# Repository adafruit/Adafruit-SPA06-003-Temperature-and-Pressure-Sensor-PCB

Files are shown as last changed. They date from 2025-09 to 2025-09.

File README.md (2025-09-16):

## Adafruit SPA06-003 Temperature + Pressure Sensor - STEMMA QT PCB

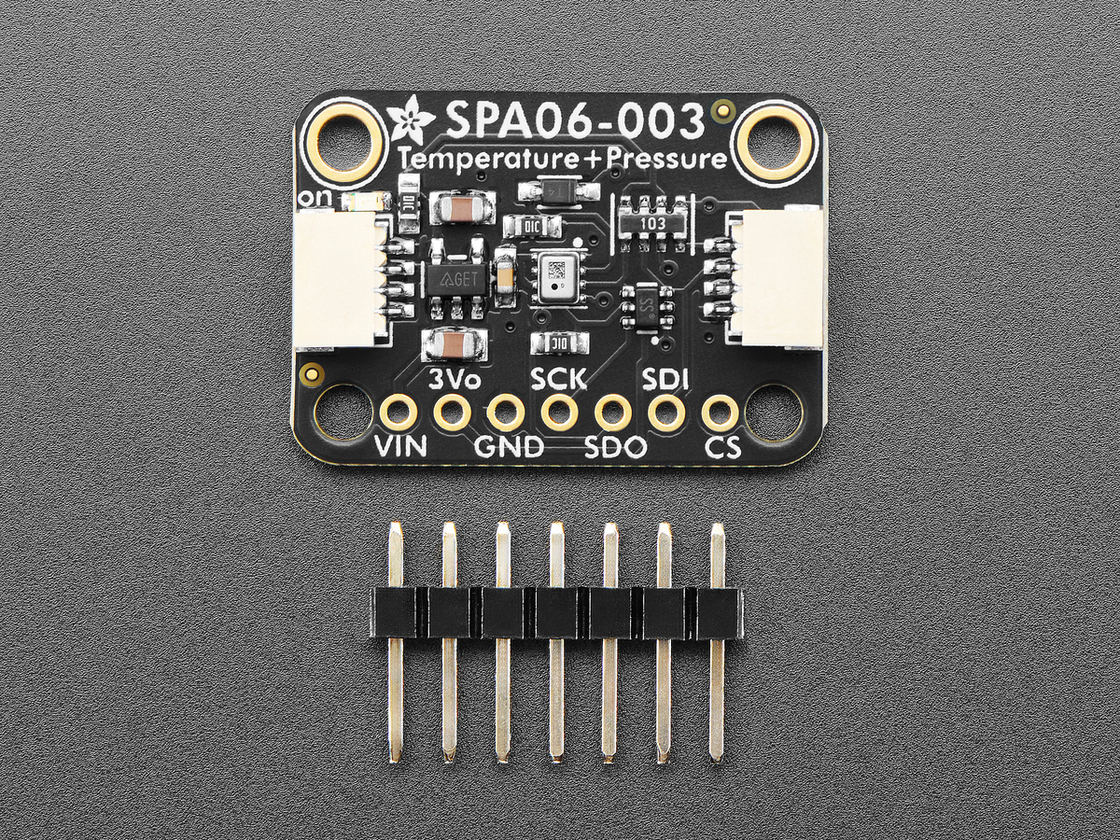
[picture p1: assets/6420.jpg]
<a href="http://www.adafruit.com/products/6420"><br/>
Click here to purchase one from the Adafruit shop</a>

PCB files for the Adafruit SPA06-003 Temperature + Pressure Sensor - STEMMA QT. 

Format is EagleCAD schematic and board layout
* https://www.adafruit.com/product/6420

### Description

This pressure sensor from Goertek is a good low-cost sensing solution for measuring barometric pressure. If you need excellent accuracy and repeatability for altitude calculations, [you can't beat the Bosch BMP series](https://www.adafruit.com/search?q=bmp) - but if you are doing basic DIY sensing, this sensor fits the bill. We see it used a lot for DIY quad copter builds and environmental sensing.

The SPA06-003 can measure from 300~1100hPa (approximately -500 to +9000m from sea level) with typical relative accuracy of ±3 Pa (equivalent to ±0.25 meter) and absolute accuracy of ±30 Pascals, or ±2.5meters. Temperature measurement accuracy is ±1°C. As we mentioned, its not going to be as accurate or precise as the latest BMP series, but the price can't be beat!

Nice sensor right? So we made it easy for you to get right into your next project. The surface-mount sensor is soldered onto a PCB and comes with a 3.3V regulator and level shifting so you can use it with a 3V or 5V logic microcontroller or single board computer without worry.

The custom made PCB is in the [STEMMA QT form factor](https://www.adafruit.com/?q=stemma%20qt%20sensor), making them easy to interface with. The [STEMMA QT connectors](https://learn.adafruit.com/introducing-adafruit-stemma-qt/what-is-stemma-qt) on either side are compatible with the [SparkFun Qwiic](https://www.sparkfun.com/qwiic) I2C connectors. This allows you to make solderless connections between your development board and the SPA06 or to chain it with a wide range of other sensors and accessories using a [compatible cable](https://www.adafruit.com/?q=stemma%20qt%20cable). [QT Cable is not included, but we have a variety in the shop](https://www.adafruit.com/?q=stemma+qt+cable&sort=BestMatch).

### License

Adafruit invests time and resources providing this open source design, please support Adafruit and open-source hardware by purchasing products from [Adafruit](https://www.adafruit.com)!

Designed by Limor Fried/Ladyada for Adafruit Industries.

Creative Commons Attribution/Share-Alike, all text above must be included in any redistribution. 
See license.txt for additional details.

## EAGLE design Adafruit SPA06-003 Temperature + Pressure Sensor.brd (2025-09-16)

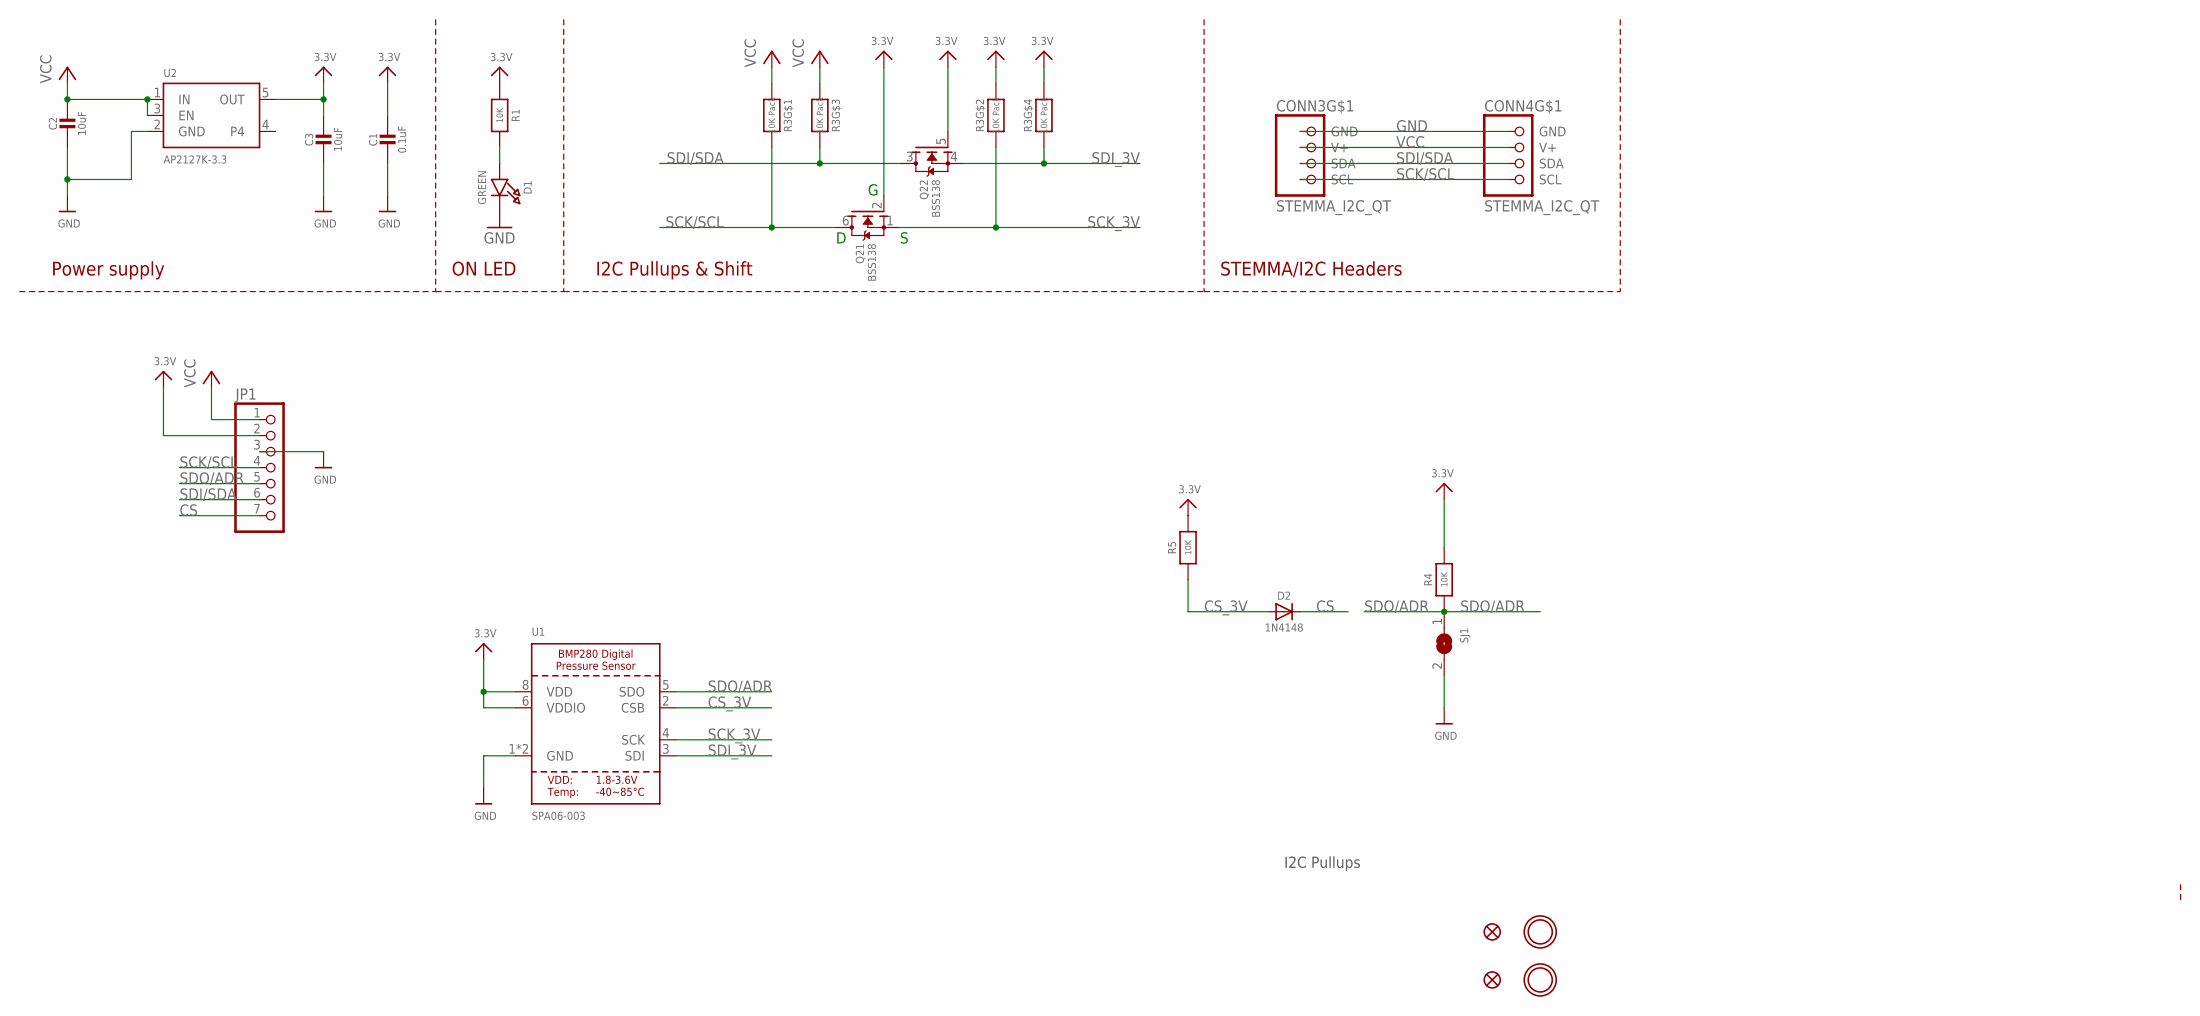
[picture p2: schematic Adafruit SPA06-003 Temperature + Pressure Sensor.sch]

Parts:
C1: 0.1uF; 0603-NO
C2, C3: 10uF; 0805-NO
CONN3, CONN4: STEMMA_I2C_QT; JST_SH4
D1: GREEN; CHIPLED_0603_NOOUTLINE
D2: 1N4148; SOD-323
FID3, FID4: FIDUCIAL_0.5MM
JP1: HEADER-1X770MIL; 1X07_ROUND_70
Q2: BSS138; SOT363
R1, R4, R5: 10K; 0603-NO
R3: 10K Pack; RESPACK_4X0603
SJ1: SOLDERJUMPER; SOLDERJUMPER_ARROW_NOPASTE
U1: SPA06-003; BMX280_COMBO
U2: AP2127K-3.3; SOT23-5
U$1, U$17: MOUNTINGHOLE2.5; MOUNTINGHOLE_2.5_PLATED

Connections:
3.3V: C1.1, C3.1, JP1.2, Q2.2 (G), Q2.5 (G), R1.1, R3.2 (1), R3.4 (1), R4.2, R5.2, U1.6 (VDDIO), U1.8 (VDD), U2.5 (OUT)
CS: D2.C, JP1.7
CS_3V: D2.A, R5.1, U1.2 (CSB)
GND: C1.2, C2.2, C3.2, CONN3.1 (GND), CONN4.1 (GND), D1.C, JP1.3, SJ1.2, U1.1 (GND), U1.7 (GND), U2.2 (GND)
unnamed: D1.A, R1.2
SCK/SCL: CONN3.4 (SCL), CONN4.4 (SCL), JP1.4, Q2.6 (D), R3.8 (2)
SCK_3V: Q2.1 (S), R3.7 (2), U1.4 (SCK)
SDI/SDA: CONN3.3 (SDA), CONN4.3 (SDA), JP1.6, Q2.3 (D), R3.6 (2)
SDI_3V: Q2.4 (S), R3.5 (2), U1.3 (SDI)
SDO/ADR: JP1.5, R4.1, SJ1.1, U1.5 (SDO)
VCC: C2.1, CONN3.2 (V+), CONN4.2 (V+), JP1.1, R3.1, R3.3 (1), U2.1 (IN), U2.3 (EN)

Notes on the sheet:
I2C Pullups & Shift
STEMMA/I2C Headers
ON LED
Power supply
I2C Pullups

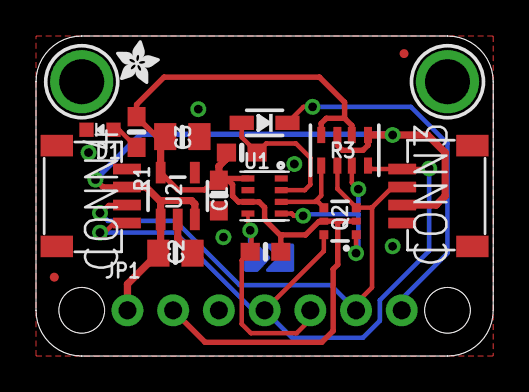
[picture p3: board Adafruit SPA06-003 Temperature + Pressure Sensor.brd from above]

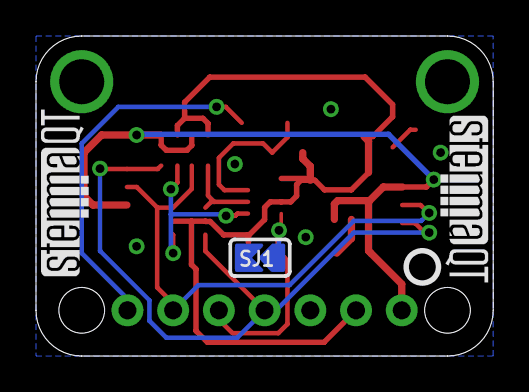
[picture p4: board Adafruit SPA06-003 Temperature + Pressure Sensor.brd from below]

Board: 2 copper layers, 25.4 x 17.8 mm, 39 parts (9 on the bottom side), 11 nets.

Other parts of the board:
PLABEL0: PLABEL0
PLABEL1: PLABEL1
PLABEL2: PLABEL2
PLABEL3: PLABEL3
PLABEL4: PLABEL4
PLABEL5: PLABEL5
PLABEL6: PLABEL6
PLABEL7: PLABEL7
PLABEL8: PLABEL8
PLABEL10: PLABEL10
PLABEL11: PLABEL11
PLABEL12: PLABEL12
PLABEL13: PLABEL13
PLABEL14: PLABEL14
PLABEL15: PLABEL15
U$4: ADAFRUIT_2.5MM
U$25: PCBFEAT-REV-040
U$30, U$31: STEMMAQT

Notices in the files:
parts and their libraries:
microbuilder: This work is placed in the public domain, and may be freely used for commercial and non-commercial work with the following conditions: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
